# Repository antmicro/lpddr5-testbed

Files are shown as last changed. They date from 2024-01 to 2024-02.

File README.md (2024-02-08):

# LPDDR5 Testbed

Copyright (c) 2023-2024 [Antmicro](https://www.antmicro.com)



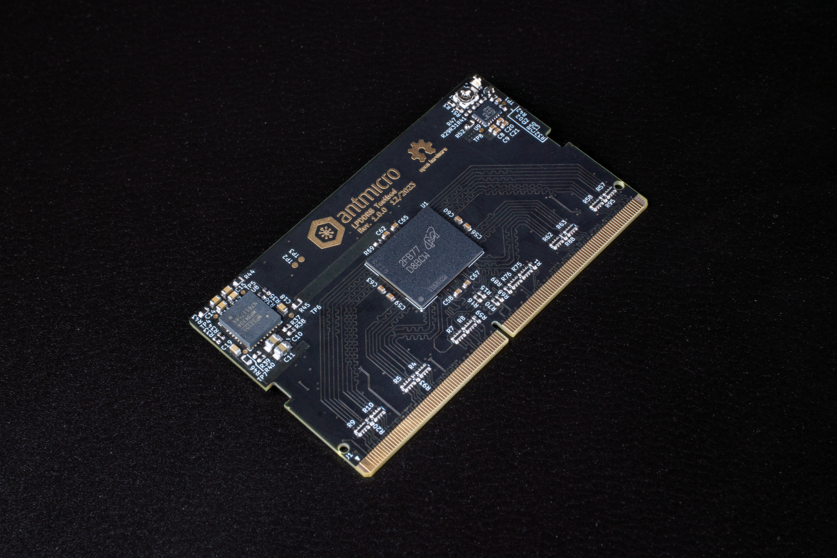
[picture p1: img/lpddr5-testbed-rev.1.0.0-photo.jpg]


## Overview

This project contains open hardware design files for an experimental test module in a mechanical form of SO-DIMM DDR5. 

The module includes a standard 315-ball WFBGA (12.4mm × 15.0mm × 0.8mm, Ø0.42 SMD) LPDDR5 RAM footprint break-routed in the SO-DIMM edge connector. 
The design files were prepared in KiCad. 

Please note that this board is not electrically compatible with off-the-shelf hot platforms accepting SO-DIMM DDR5 memory modules. 
It is compatible with [this](https://github.com/antmicro/sodimm-ddr5-tester) test platform.

## Project structure

The main project directory contains KiCad PCB project files, a LICENSE and README. 
The remaining files are stored in the following directories:

* `lib` - contains the component libraries
* `img` - contains graphics for this README
* `doc` - contains PDF schematic
* `assets` - contains visual assets for showcasing this board on Antmicro [Open Hardware Portal](https://openhardware.antmicro.com).

## Licensing

This project is published under the [Apache-2.0](LICENSE) license.

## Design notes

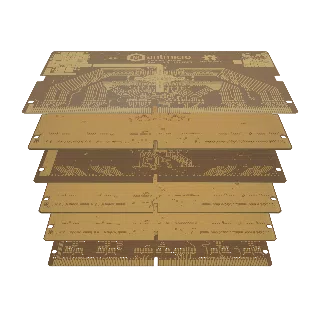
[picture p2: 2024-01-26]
assets/previews/layer1_thumbnail.webp

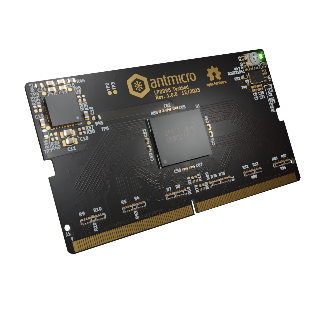
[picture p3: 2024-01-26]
assets/previews/leftT_thumbnail.png

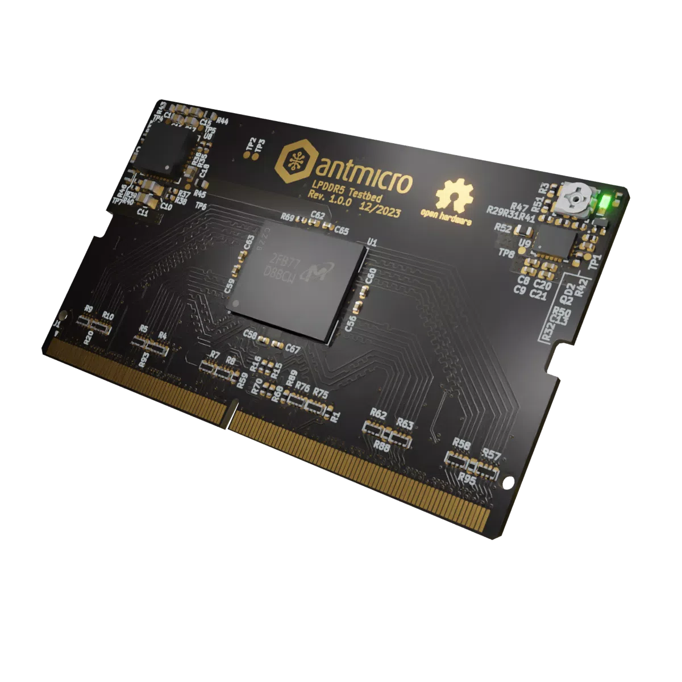
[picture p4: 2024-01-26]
assets/previews/rightT.webp

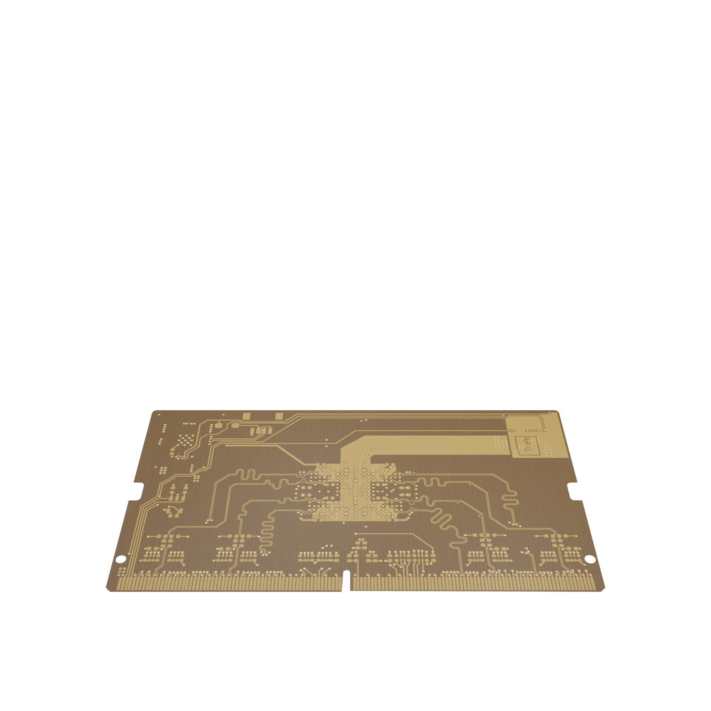
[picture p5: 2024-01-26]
assets/previews/layer6.png

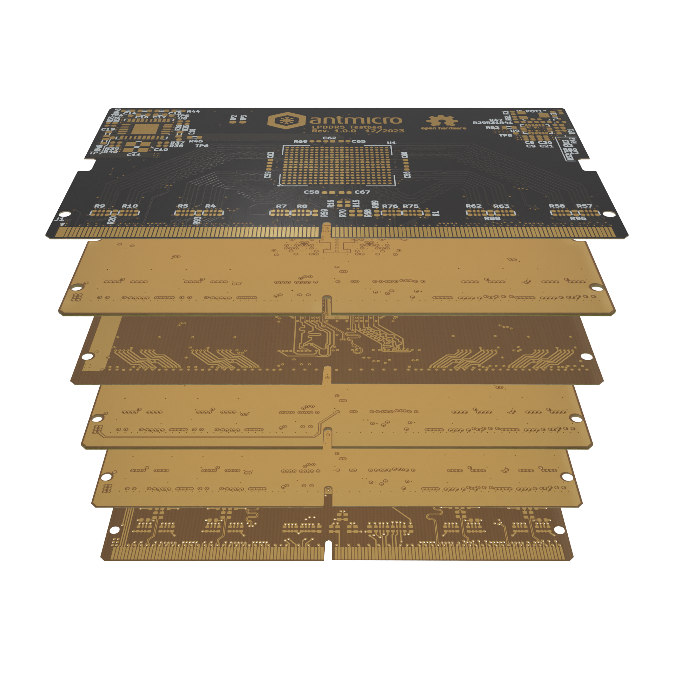
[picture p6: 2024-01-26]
assets/previews/stackup.png

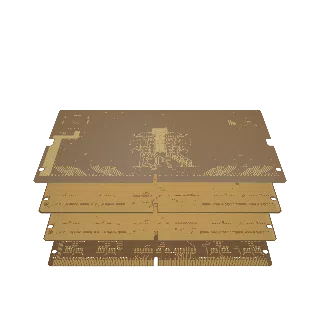
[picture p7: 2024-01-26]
assets/previews/layer3_thumbnail.webp

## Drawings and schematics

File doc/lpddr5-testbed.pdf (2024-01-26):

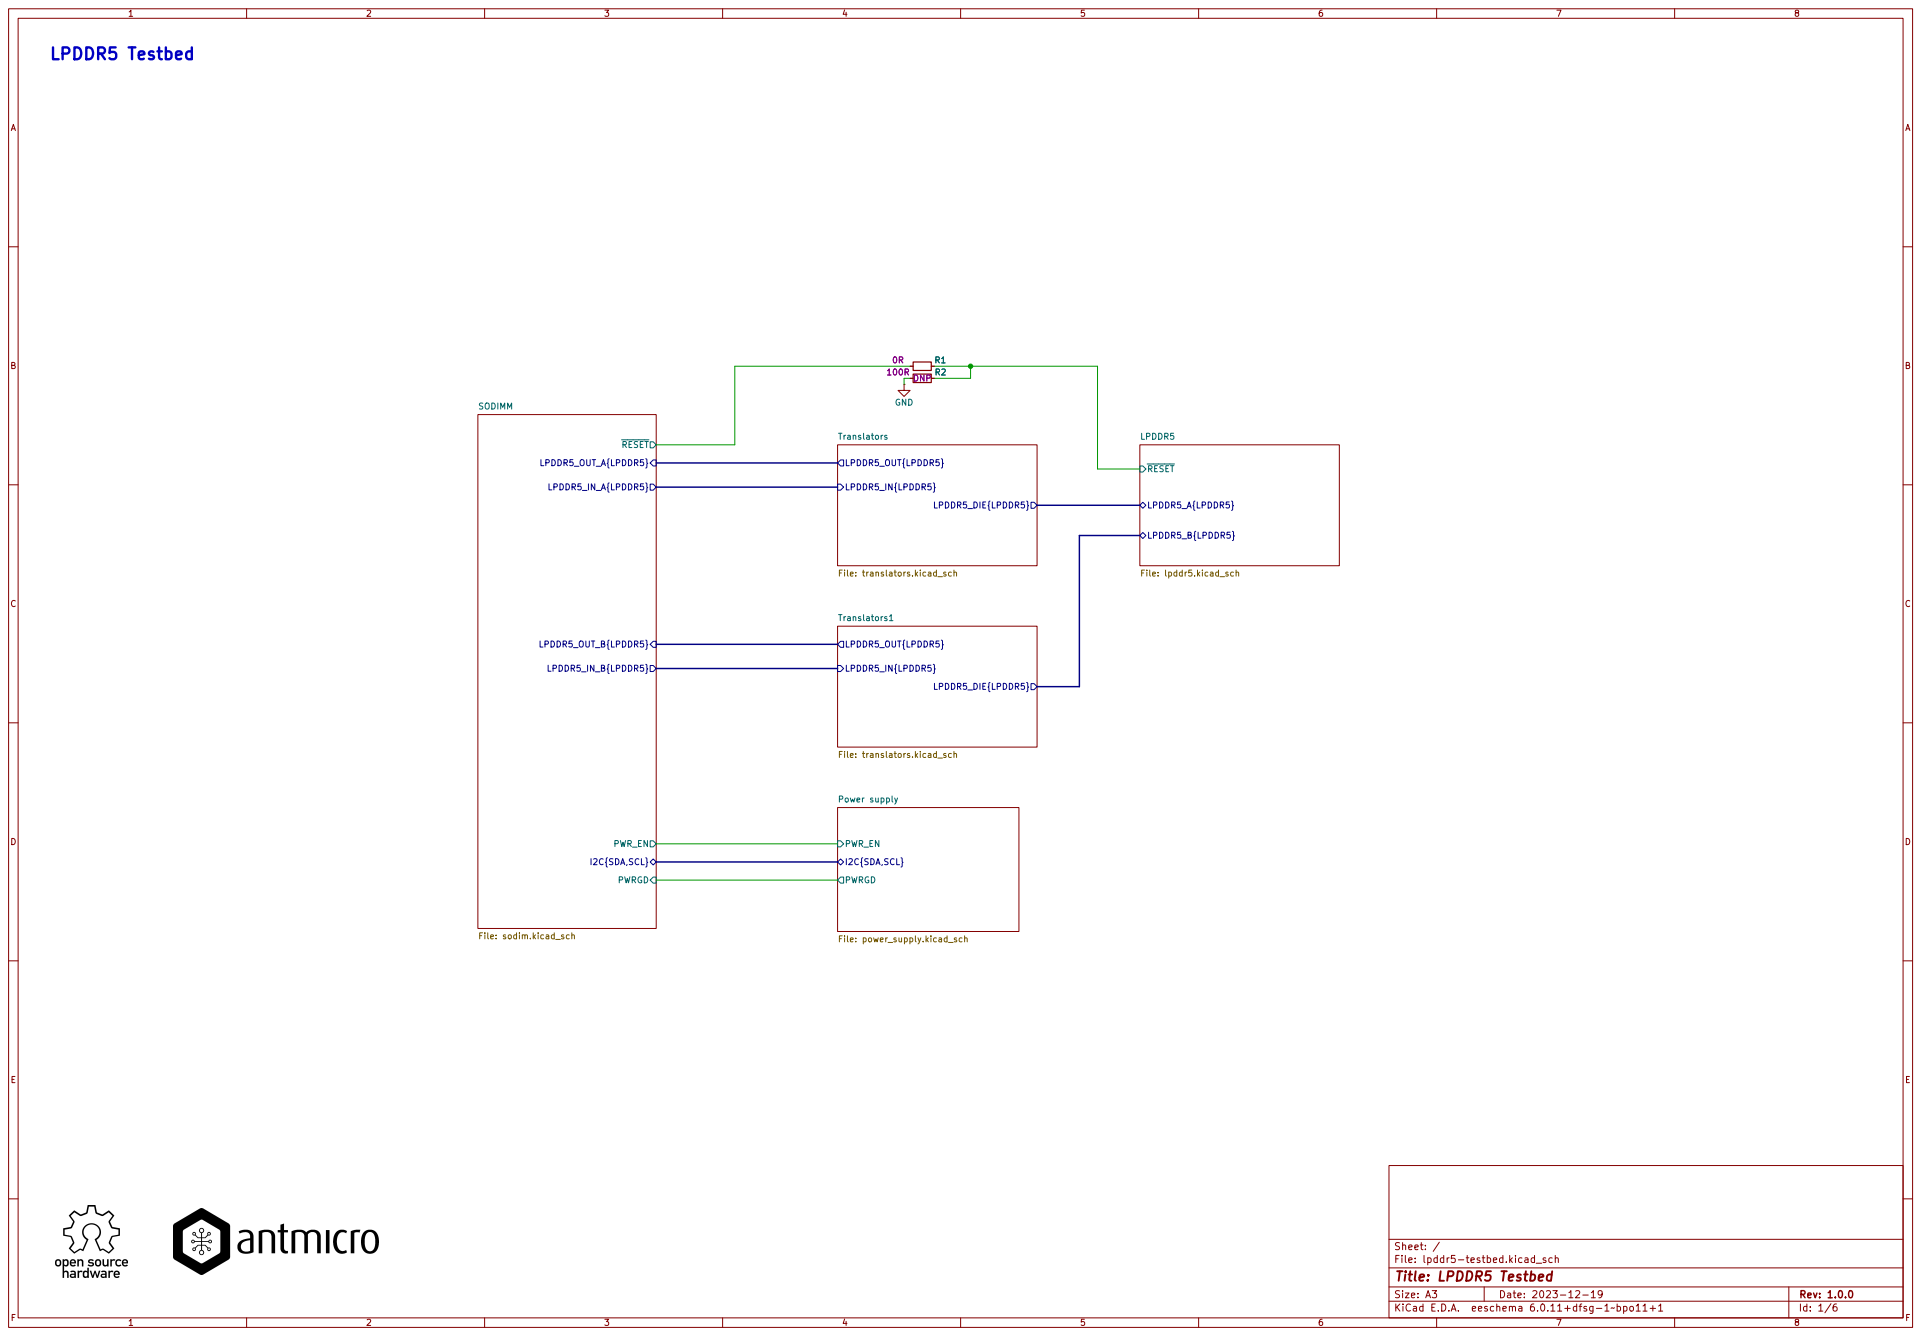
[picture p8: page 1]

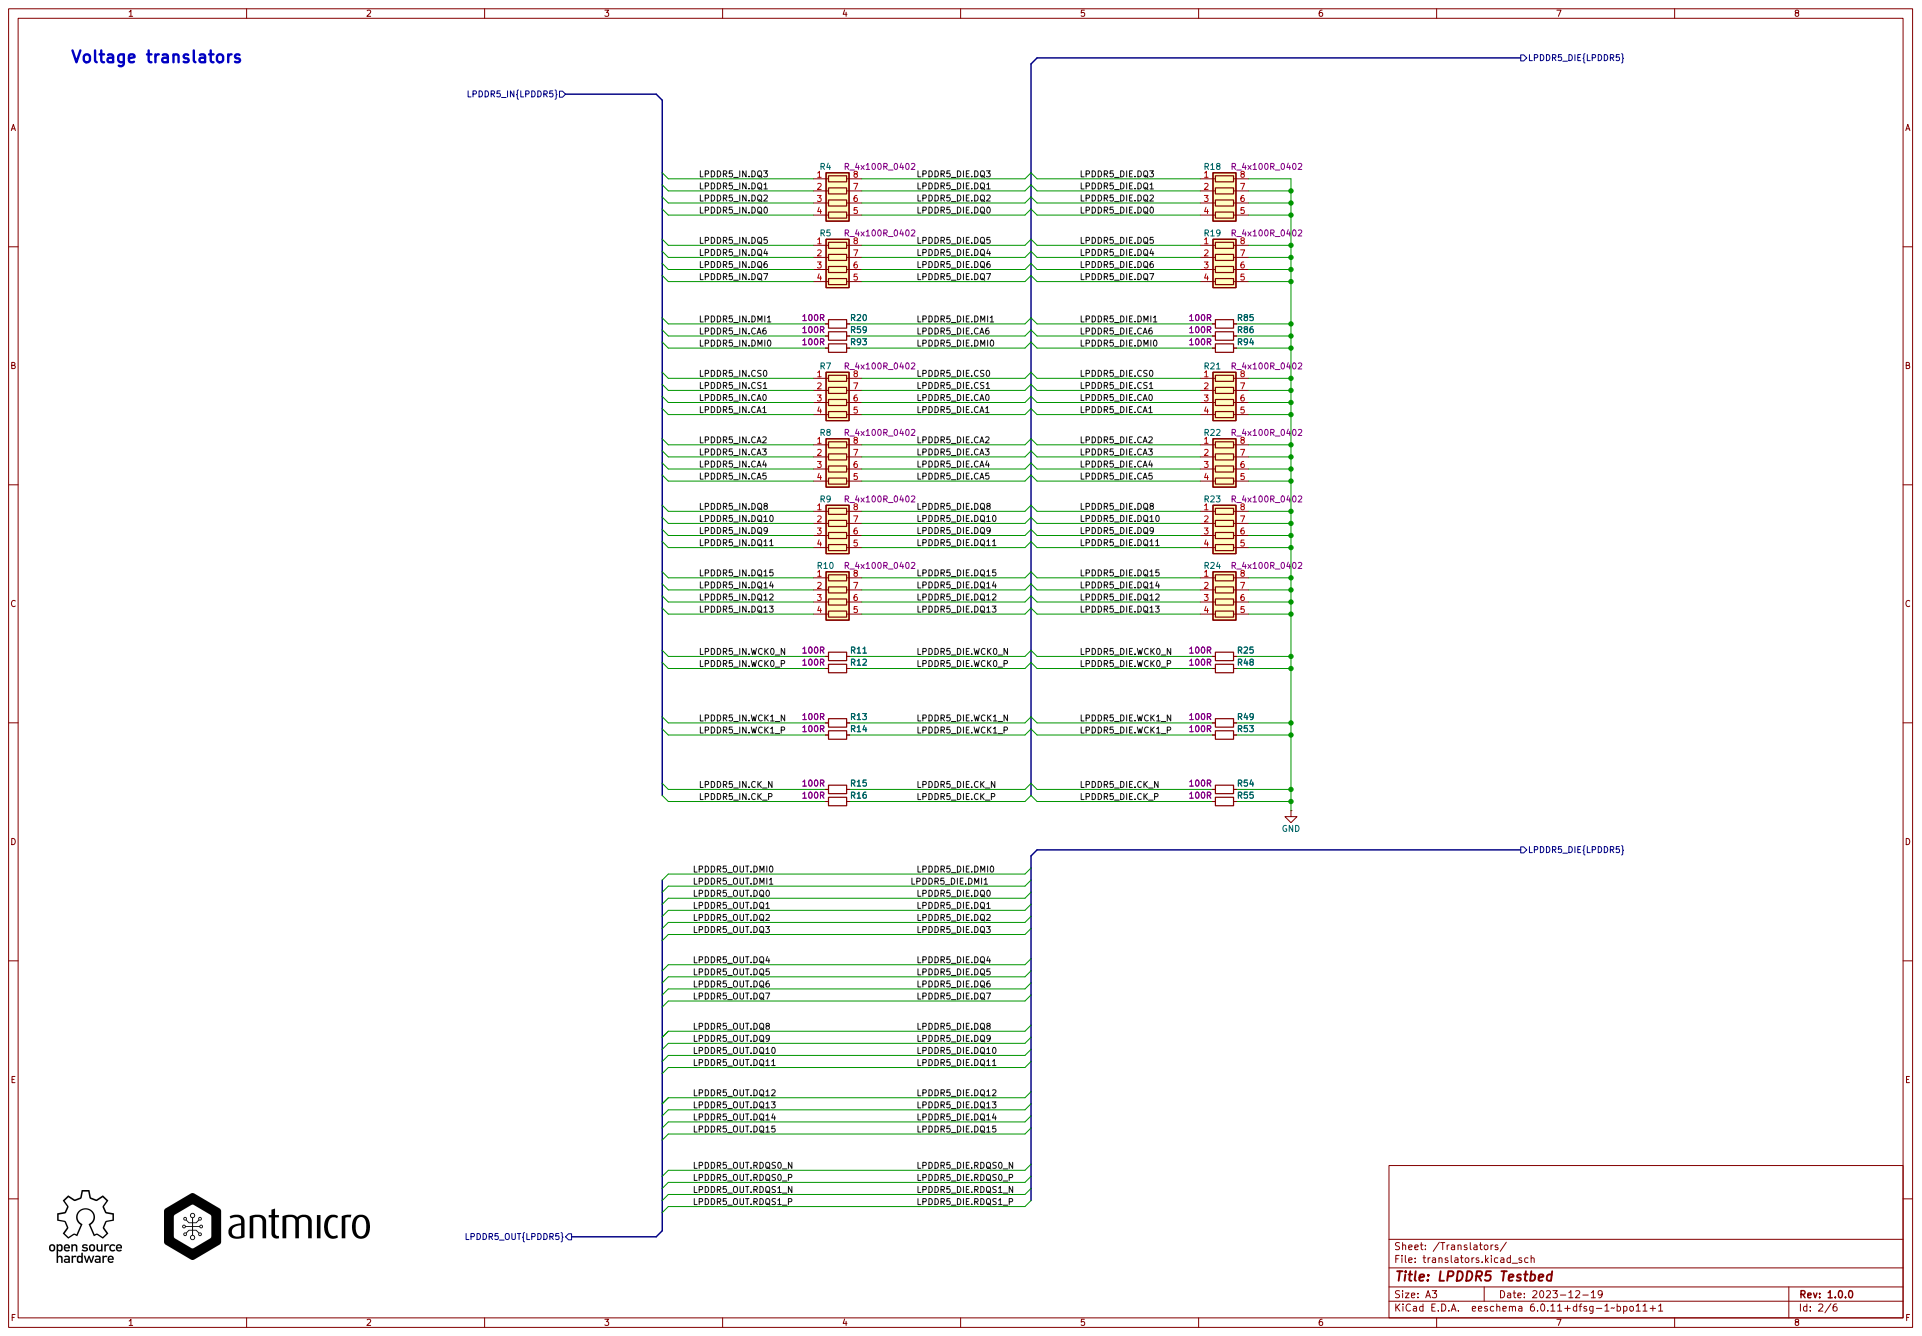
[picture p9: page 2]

File: translators.kicad_sch Sheet: /Translators/
Id: 2/6 Title: LPDDR5 Testbed

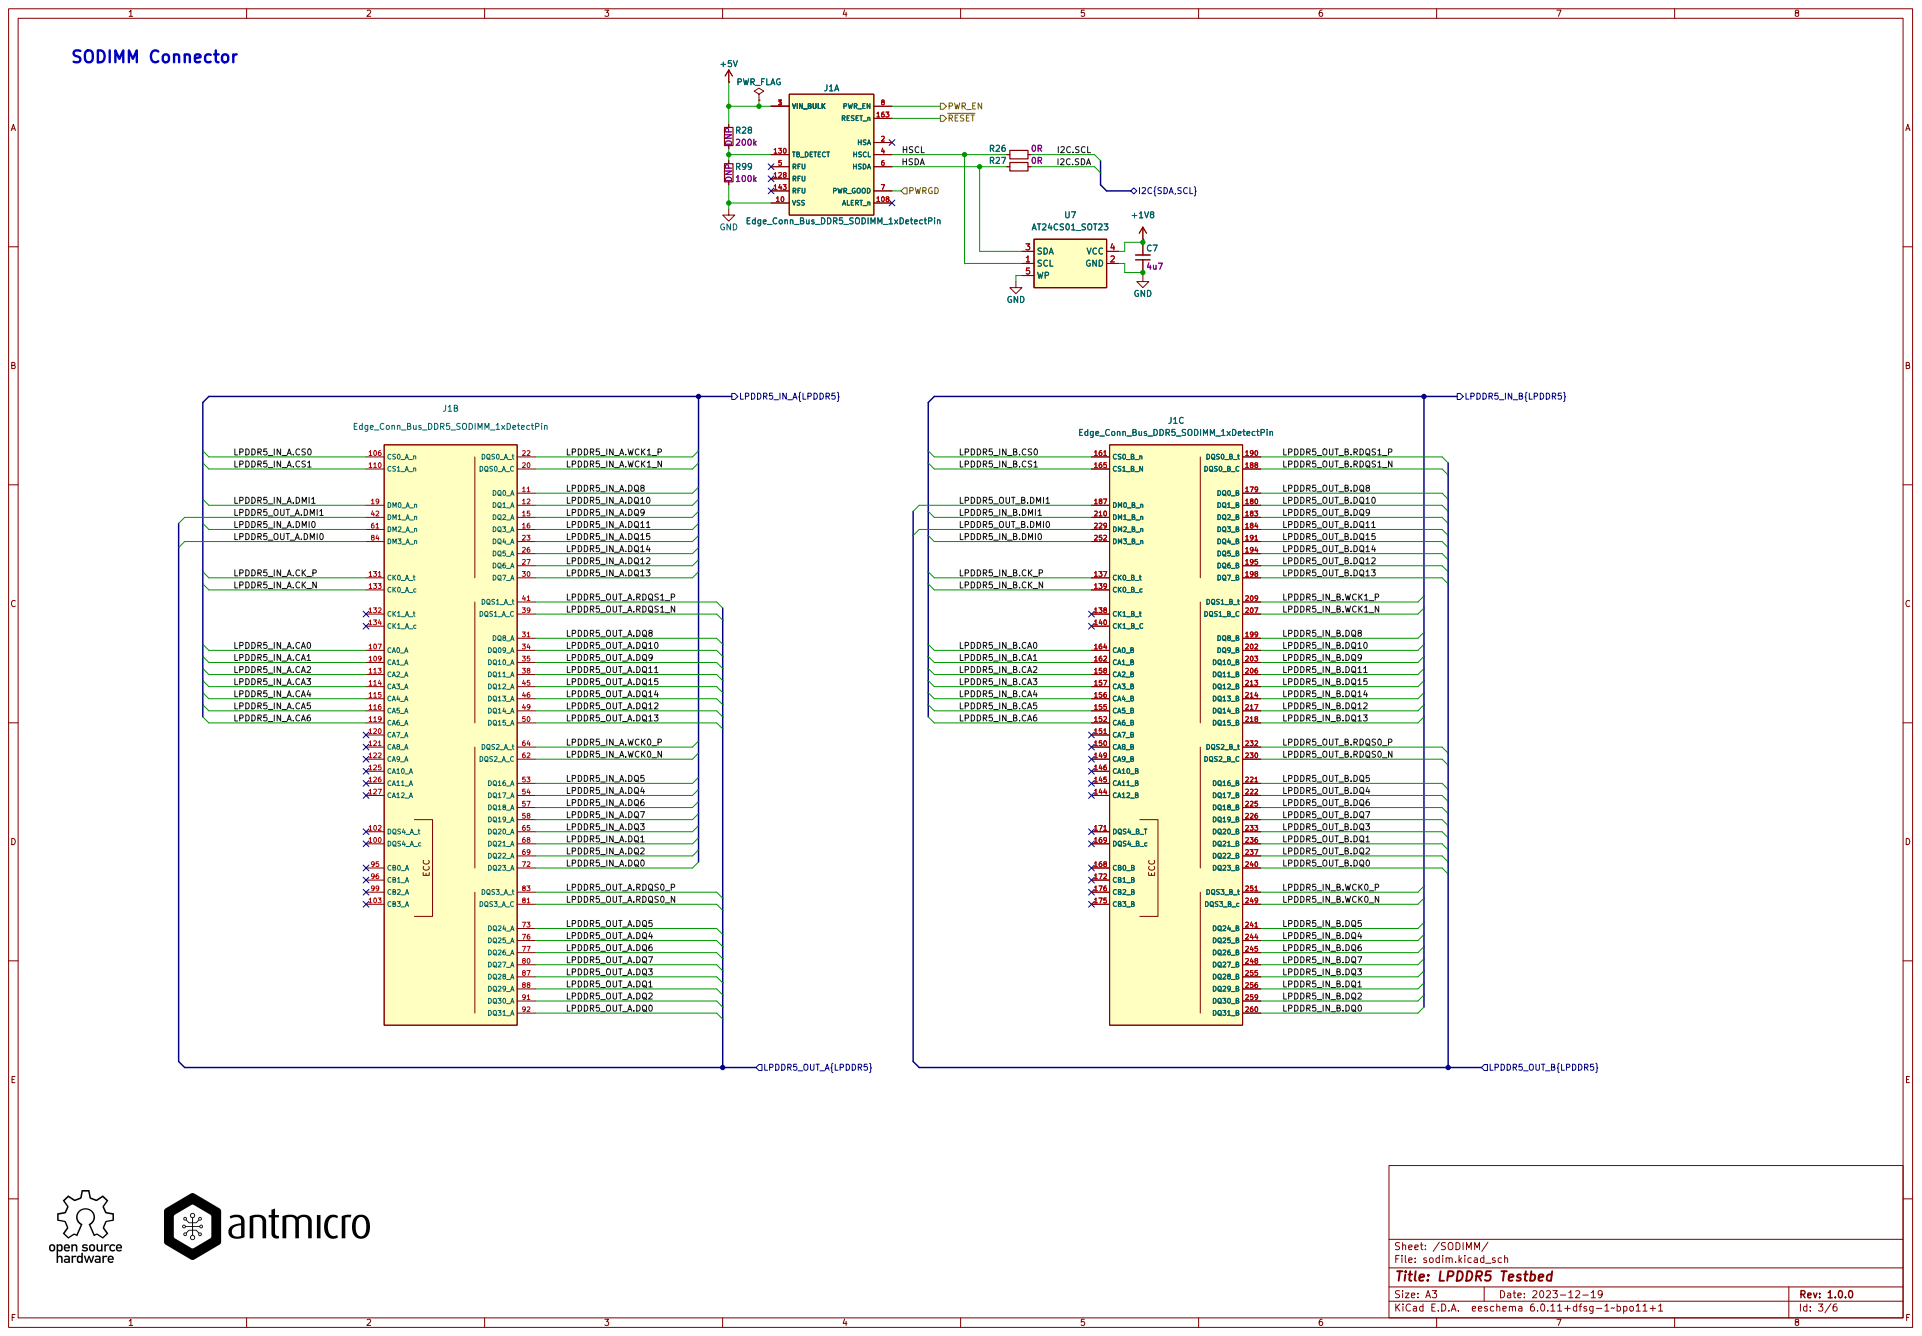
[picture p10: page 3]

File: sodim.kicad_sch Sheet: /SODIMM/
Id: 3/6 Title: LPDDR5 Testbed

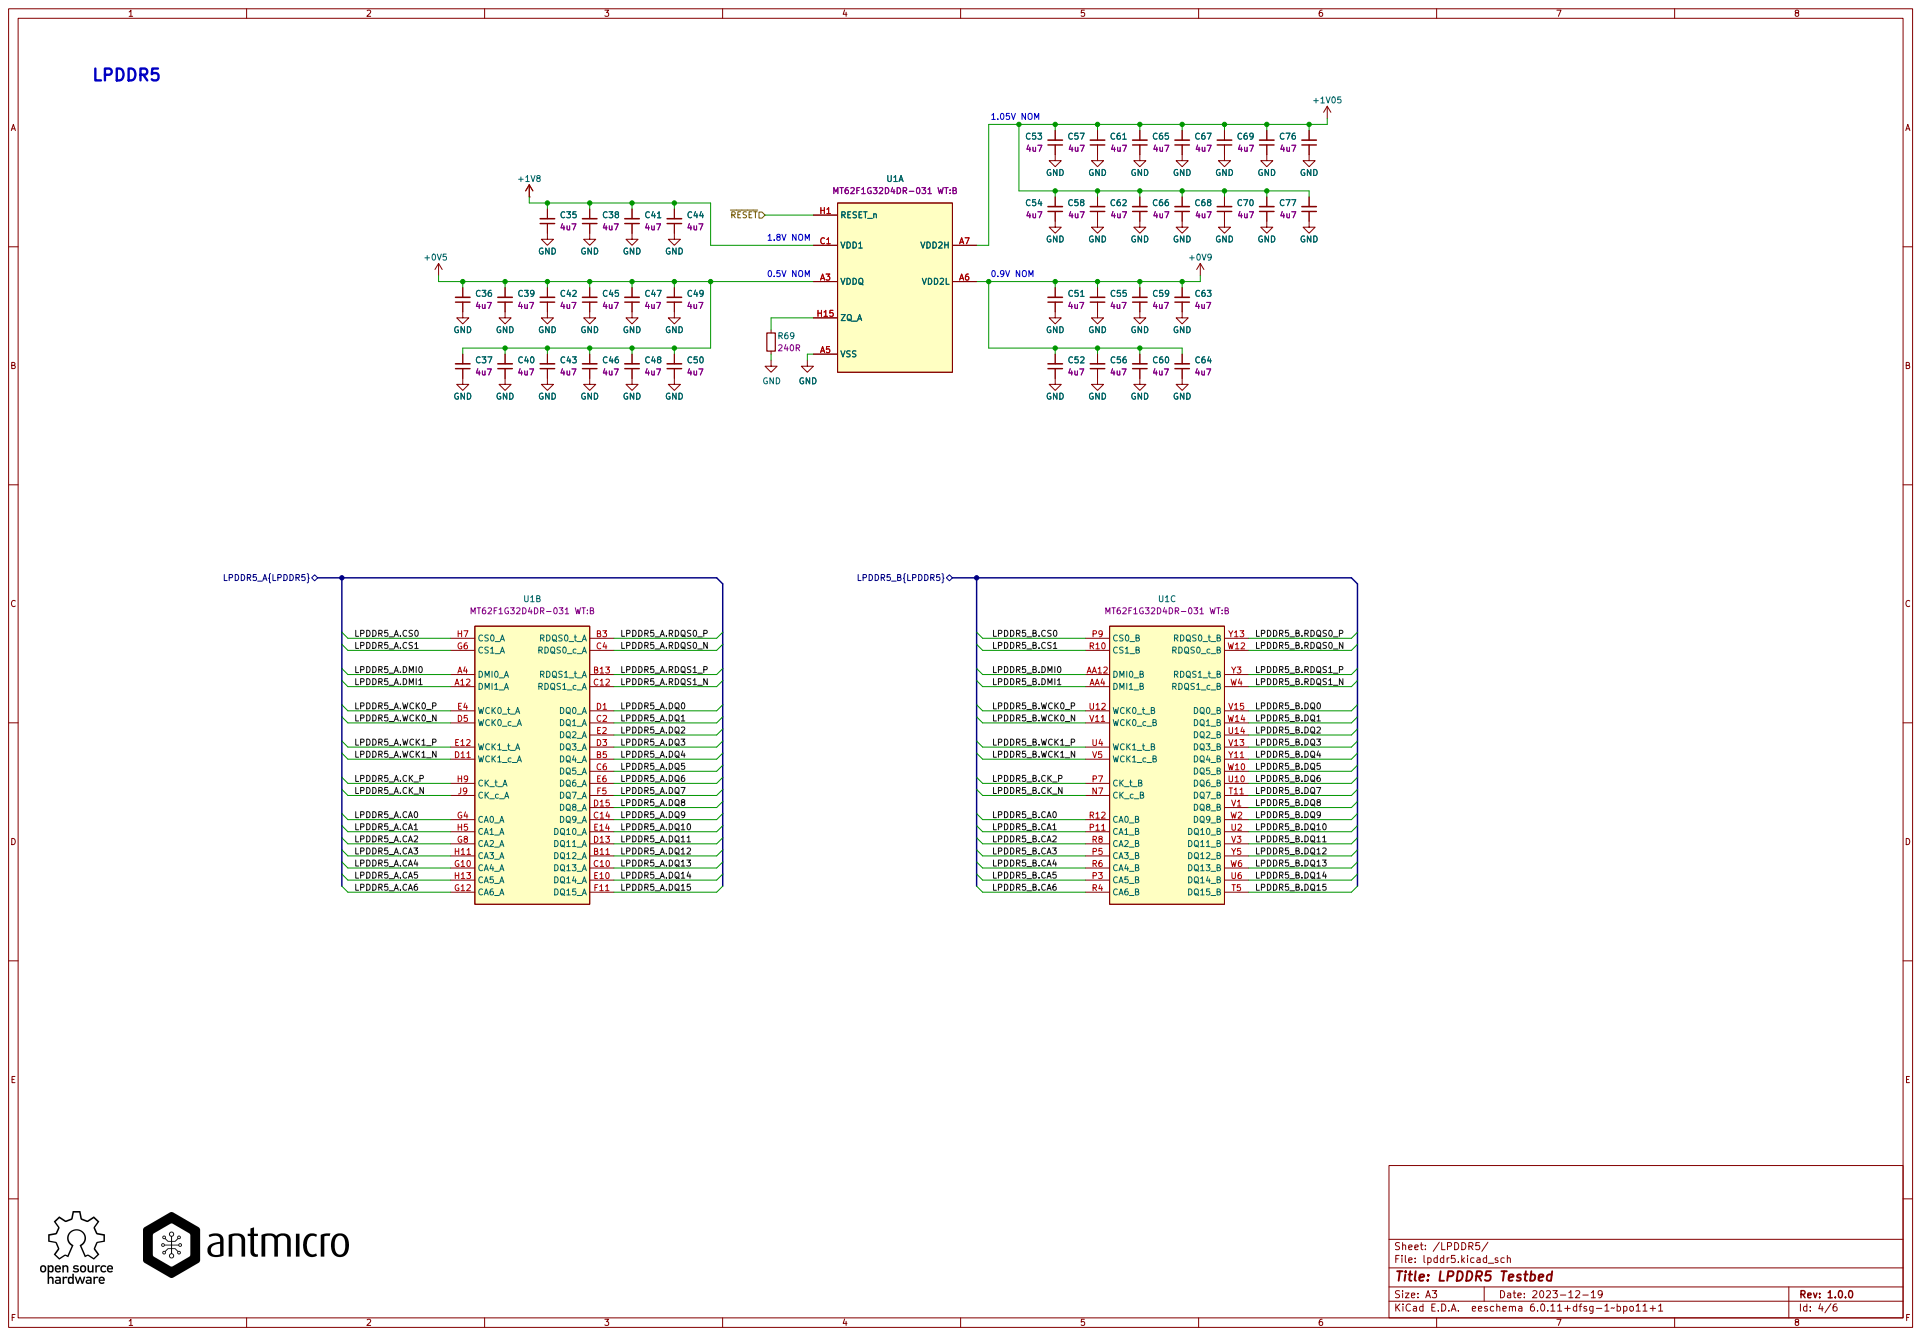
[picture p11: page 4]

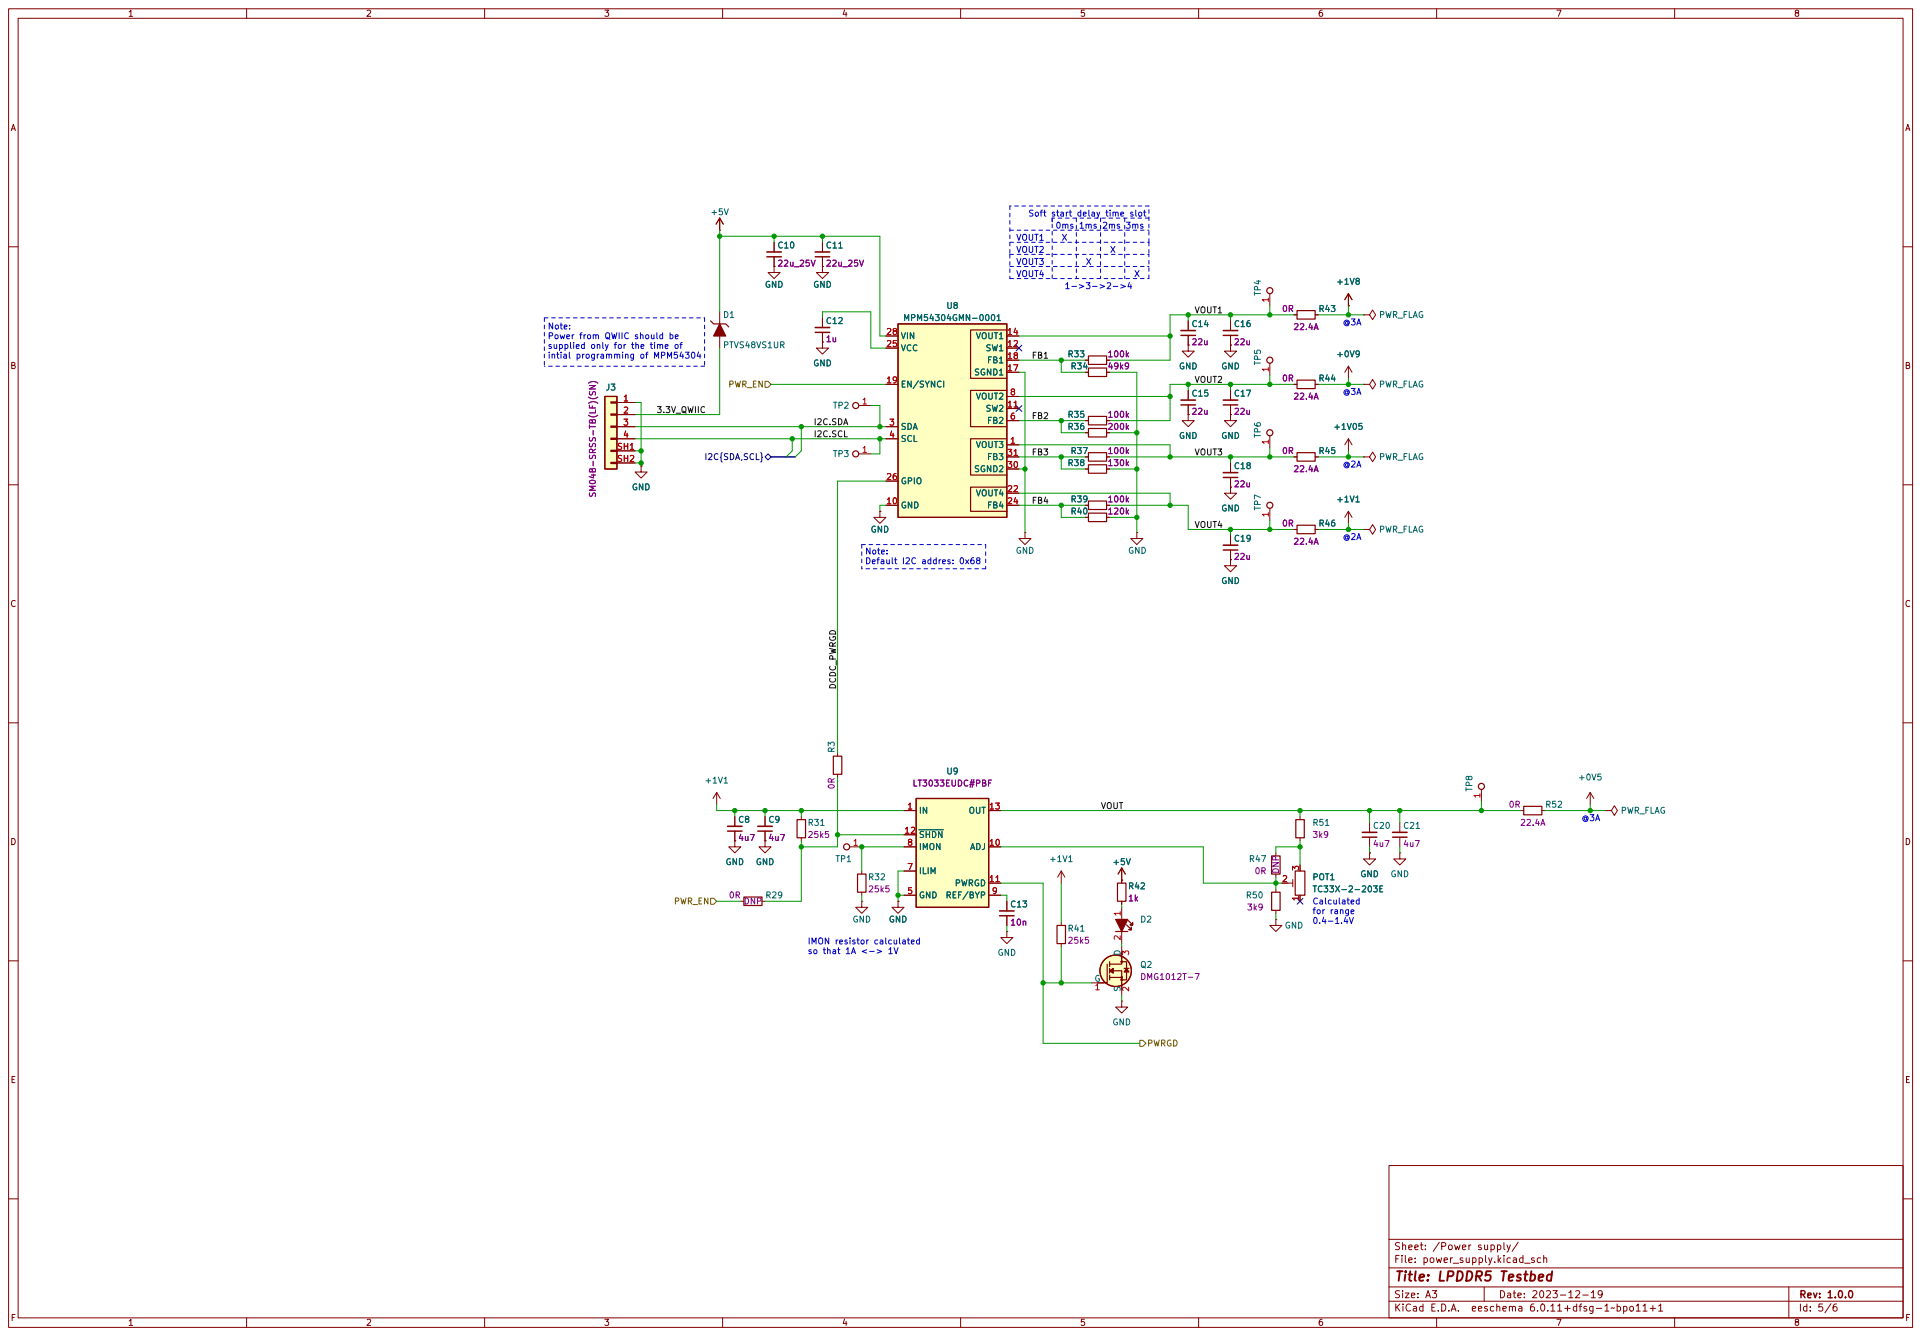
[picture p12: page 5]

VOUT4 VOUT1

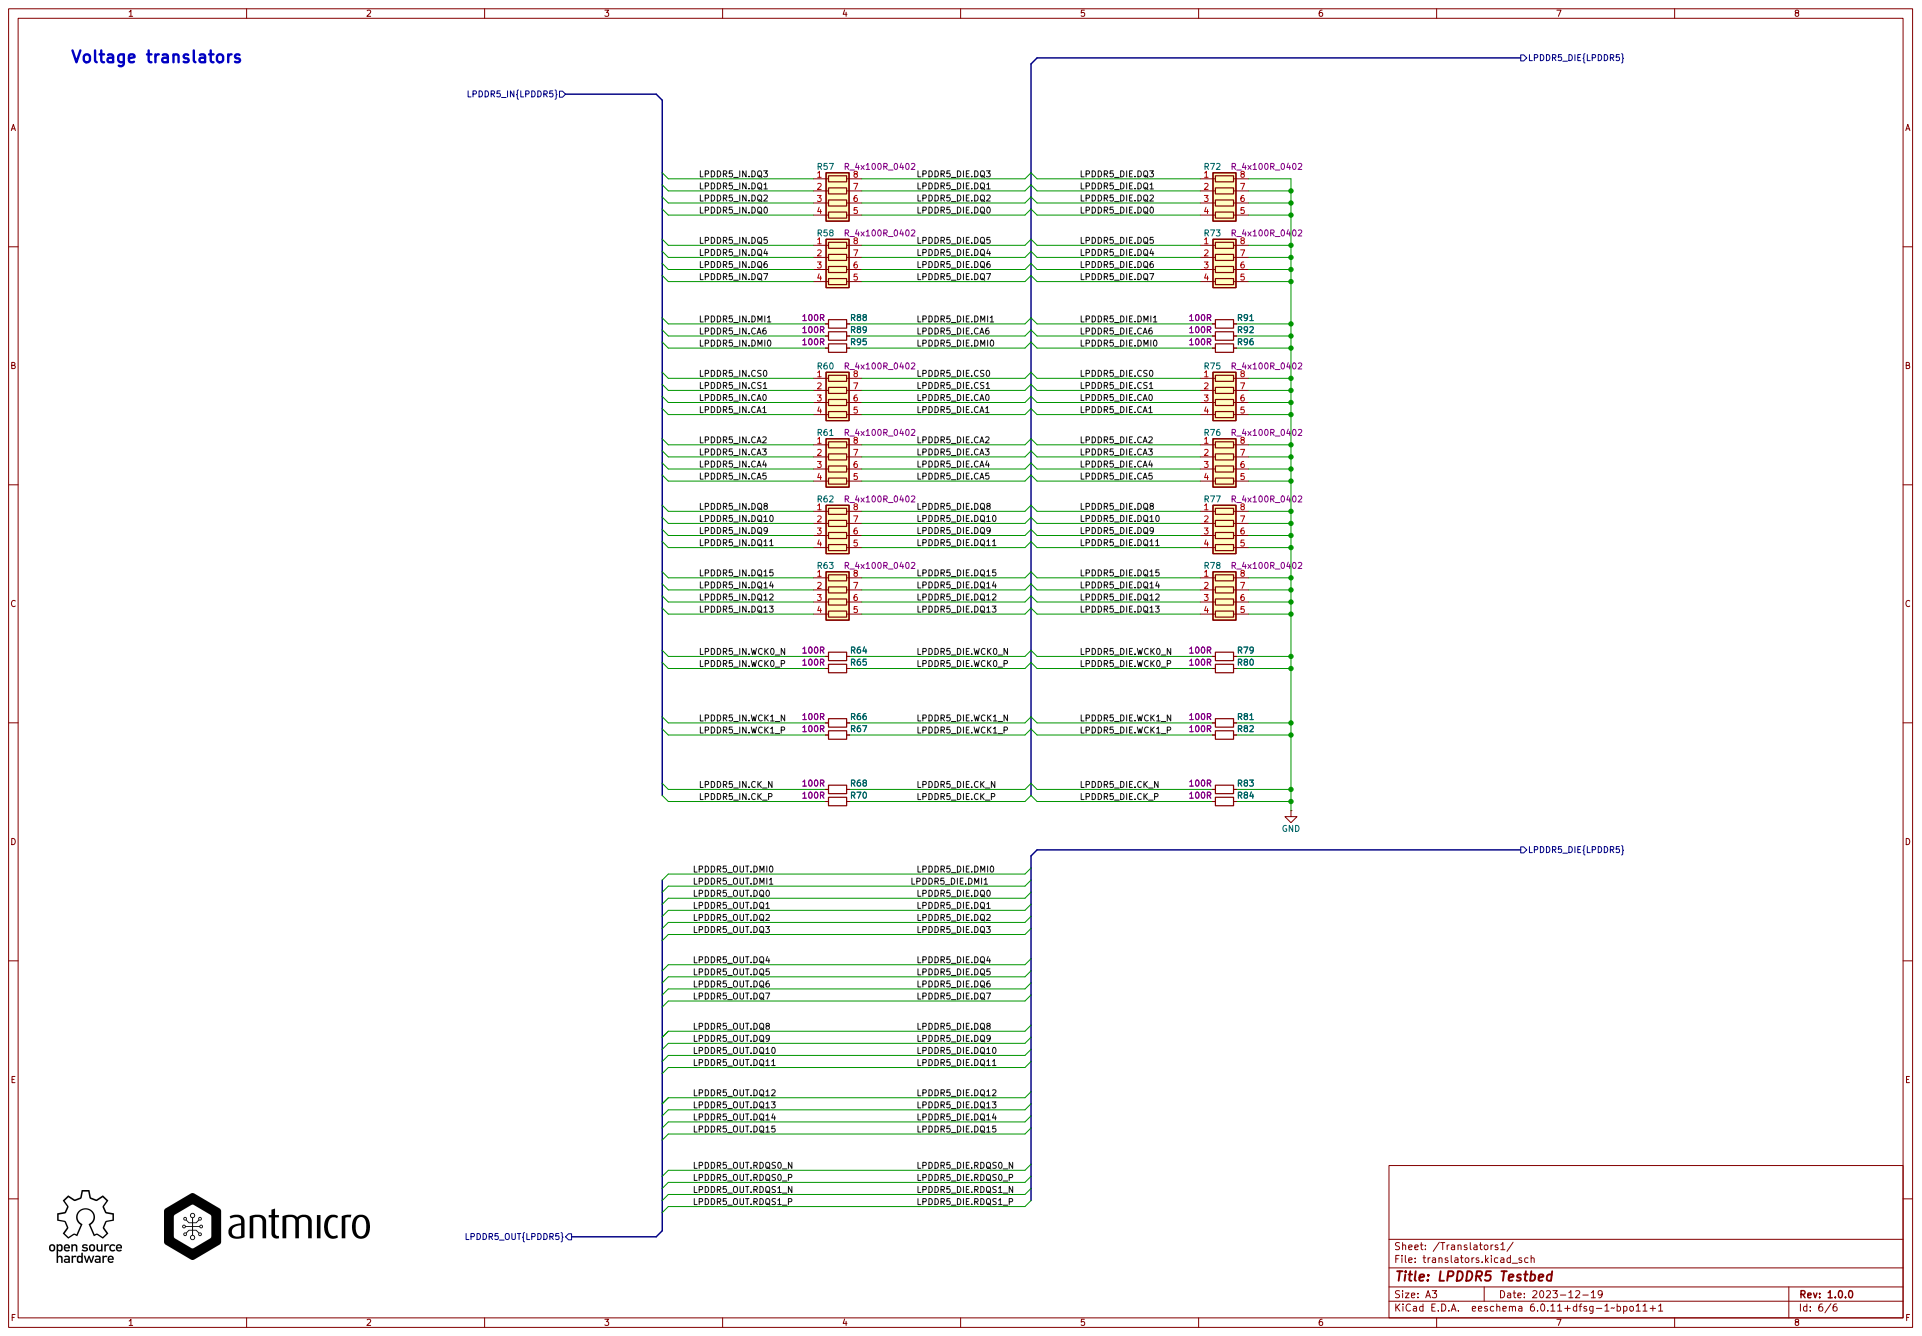
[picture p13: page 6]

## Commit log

2023-12-19 [#52835] initial commit
    Include DDR5 SO-DIMM edge connector
    [ldo.kicad_sch, lpddr5-sodimm.kicad_sch, lpddr5.kicad_sch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]
2023-12-21 [#52835] schematics: update DDR5 SODIMM edge symbol
    [lpddr5-sodimm.kicad_sch, sodim.kicad_sch]
2023-12-21 [#52835] schematics: align reference designators and values
    [sodim.kicad_sch]
2023-12-21 [#52835] schematics: update LDO subsheet
    LDO subsheet should not contain feedback so that this sheet could be reused
    [ldo.kicad_sch]
2023-12-21 [#52835] schematics: add I2C line, VIN_BULK is 5V
    [sodim.kicad_sch]
2023-12-21 [#52835] schematics: add nominal rails voltage to lpddr5
    [lpddr5.kicad_sch]
2023-12-21 [#52835] schematics: add MPM54304GMN to Power Supply, update sheet
    [power_supply.kicad_sch]
2023-12-21 [#52835] schematics: connect I2C on root sheet
    [lpddr5-sodimm.kicad_sch]
2023-12-21 [#52835] schematics: update LPDDR5 connections, finish translators subsheet
    [lpddr5.kicad_sch, sodim.kicad_sch, translators.kicad_sch]
2023-12-21 [#52835] schematics: update power supply section
    [power_supply.kicad_sch]
2023-12-21 [#52835] schematics: update connections on root sheet
    [lpddr5-sodimm.kicad_sch]
2023-12-22 [#52536] schematics: setup resistor dividers for DCDC converter
    [lpddr5-sodimm.kicad_sch, power_supply.kicad_sch, sodim.kicad_sch]
2023-12-22 [#52536] schematics: adjust outputs based on LPDDR5 voltage ramps
    [lpddr5-sodimm.kicad_sch, power_supply.kicad_sch]
2023-12-22 [#52536] schematics: update I2C connection
    [lpddr5-sodimm.kicad_sch, lpddr5.kicad_sch, sodim.kicad_sch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]
2023-12-29 [#52835] schematics: update components after standardization
    [lpddr5-sodimm.kicad_sch, lpddr5.kicad_sch, power_supply.kicad_sch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]
2023-12-29 [#52974] pcb: import components from schematic
2023-12-29 [#52835] schematics: update translators pinout to for better package breakout
    [lpddr5-sodimm.kicad_sch, power_supply.kicad_sch, sodim.kicad_sch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]
2023-12-29 [#52536] schematics: fix DCDC feedback resistors connection
    [lpddr5-sodimm.kicad_sch, power_supply.kicad_sch]
2023-12-29 [#52536] schematics: use voltage divider to detect pin
    [lpddr5-sodimm.kicad_sch, power_supply.kicad_sch, sodim.kicad_sch]
2023-12-29 [#52536] schematics: add additional decoupling to DDR die
    [lpddr5-sodimm.kicad_sch, lpddr5.kicad_sch, translators.kicad_sch]
2023-12-29 [#52974] pcb: initial placement of components ardound DDR die
2023-12-29 [#52835] schematics: remove some 0R to simplify translator layout
    [lpddr5-sodimm.kicad_sch, translators.kicad_sch]
2023-12-29 [#52974] pcb: placement of DCDC section and update pcb from schematic
2023-12-29 [#52536] 52835: use resistors dividers instead of translators
    [lpddr5-sodimm.kicad_sch, sodim.kicad_sch, translators.kicad_sch]
2023-12-29 [#52974] pcb: remove translators, add resistors, update layout
2023-12-29 [#52835] schematics: replace array resistors with 0402
    [lpddr5-sodimm.kicad_sch, sodim.kicad_sch, translators.kicad_sch]
2023-12-29 [#52974] pcb: place resistors, basic routing
2023-12-29 [#52974] pcb: add 0.5V power plane
2023-12-29 [#52974] pcb: poc route using resistor arrays back
    [lpddr5-sodimm.kicad_sch, sodim.kicad_sch, translators.kicad_sch]
2023-12-29 [#52835] schematics: futher replacement of 0402R with resistor arrays
    [lpddr5-sodimm.kicad_sch, translators.kicad_sch]
2023-12-29 [#52974] pcb: route DQ_A[0:7] using resistor arrays
2023-12-29 [#52835] schematics: assign new netclasses
    [lpddr5-sodimm.kicad_sch, translators.kicad_sch]
2023-12-29 [#52974] pcb: start routing CA_A
2023-12-29 [#52974] schematics: final connection of the A side of the die
    [sodim.kicad_sch, translators.kicad_sch]
2023-12-29 [#52974] pcb: connect die A side to the sodimm connector using resistor arrays and 0402 resistors
2023-12-29 [#52835] schematics: swap pins within groups
    [sodim.kicad_sch]
2023-12-29 [#52974] pcb: start routing channel B
2023-12-29 [#52835] update project name
    [lpddr5-sodimm.kicad_sch, lpddr5-testbed.kicad_sch, lpddr5.kicad_sch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]
2023-12-29 [#52835] schematics: remove unnecessary resistors
    [lpddr5-testbed.kicad_sch, translators.kicad_sch]
2023-12-29 [#52974] pcb: place side B resistors
2023-12-29 [#52974] pcb: disable reference designators
2023-12-29 [#52835] schematics: swap DMI pins on side B
    [sodim.kicad_sch]
2023-12-29 [#52974] pcb: continue side B layout
2023-12-29 [#52835] schematics: update dc/dc symbol from lib
    [lpddr5-testbed.kicad_sch, power_supply.kicad_sch]
2023-12-29 [#52974] pcb: update dc/dc footprint from lib
2023-12-29 [#52974] pcb: side B layout
2023-12-29 [#52974] pcb: finish routing, DRC clean
    [sodim.kicad_sch]
2023-12-29 Add schematic PDF
2024-01-03 [#53267] schematic: fix bus connections
    [sodim.kicad_sch]
2024-01-03 [#53267] schematic: improve power supply sequencing and power good signal
    [lpddr5-testbed.kicad_sch, power_supply.kicad_sch, sodim.kicad_sch]
2024-01-03 [#53267] pcb: start layout improvement
2024-01-03 [#53267] pcb: continue layout improvement
2024-01-03 [#53267] pcb: drc clean
2024-01-05 [#53267] pcb: length match diff pairs
2024-01-10 [#53670] sch: remove not needed voltage divider
    [lpddr5-testbed.kicad_sch]
2024-01-10 [#53670] pcb: fix lenght matching of diff pairs and CS signals
2024-01-11 Move passives away from LPDDR5 IC on top layer, add PCB SHA marking
2024-01-26 Add OHP assets
    [stackup.csv]
